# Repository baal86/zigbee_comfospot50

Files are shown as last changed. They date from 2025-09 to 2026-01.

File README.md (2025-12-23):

# Zigbee Comfospot 50
Hardware module to integrate Comfospot 50 ventilation system with ESP32-H2 zigbee enabled controller. Heavily based on https://github.com/lorenzspenger/comfospot-50 but using the ESP32-H2 and Zigbee.

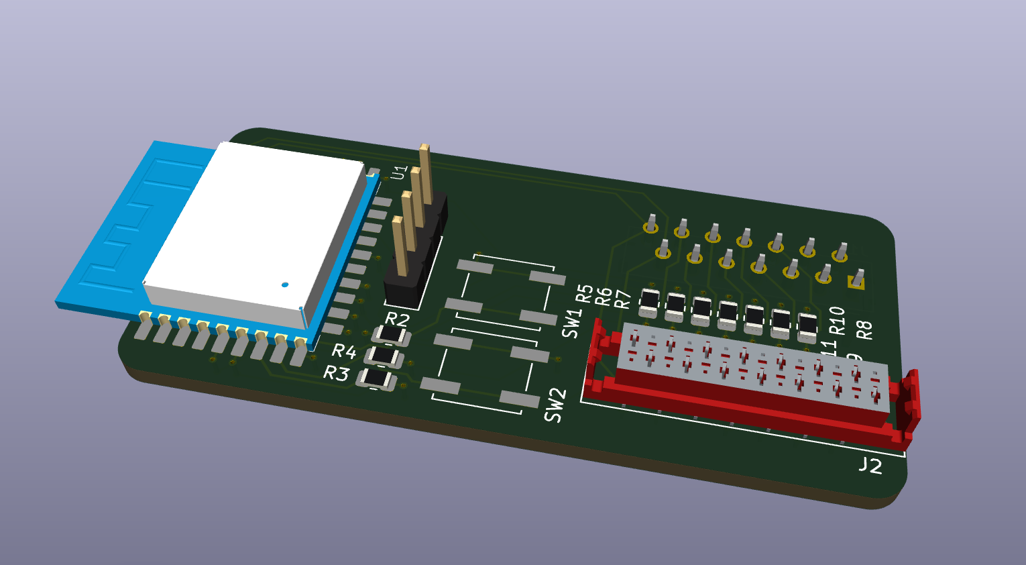
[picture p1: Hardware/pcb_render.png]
PCB Rendering


## Hardware 
Contains a Kicad project to produce the hardware module that plugs inbetwen the Comfospot 50 main board and the user interface panel.

> The latest change to the hardware (shortening the PCB for mechanical fit) was not tested in production. I used a previous revision PCB and shortened it with a file. I will probably never produce the latest version.

## ESPHome
Contains the .yaml file to build the firmware using ESPHome. The `partitions_zb.csv` file is required at the time of writing for zigbee support! OTA is not supported by esphome-zigbee so the image must be programmed using a USB to serial (3.3V TTL levels) converter.

## zigbee2mqtt
Contains the external converter than needs to be provided to Zigbee2MQTT to recognize the device and present it to home assistant. It is currently very basic but is working and the fan unit can be controlled by selecting the desired step.

## TODO
Honestly, it works for me as is right now so don't expect any updates soon. Debugging is quite a pain due to the lack of OTA updates and wireless logging. What I could imagine:

- Support the filter change LED
- More advanced control of fan levels as in https://github.com/lorenzspenger/comfospot-50. My implementation is quite primitive.
- Support control of exhaust/circulation modes.

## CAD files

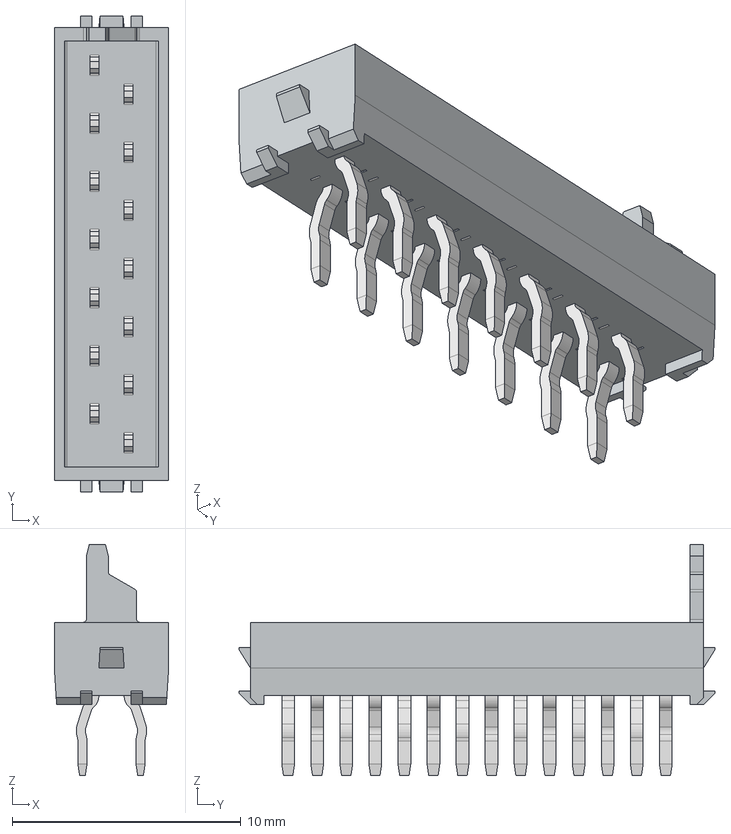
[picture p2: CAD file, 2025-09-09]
Hardware/local.step3d/J_Wurth_WR-MM_690357101472.step
5.00 x 20.8 x 10.1 mm

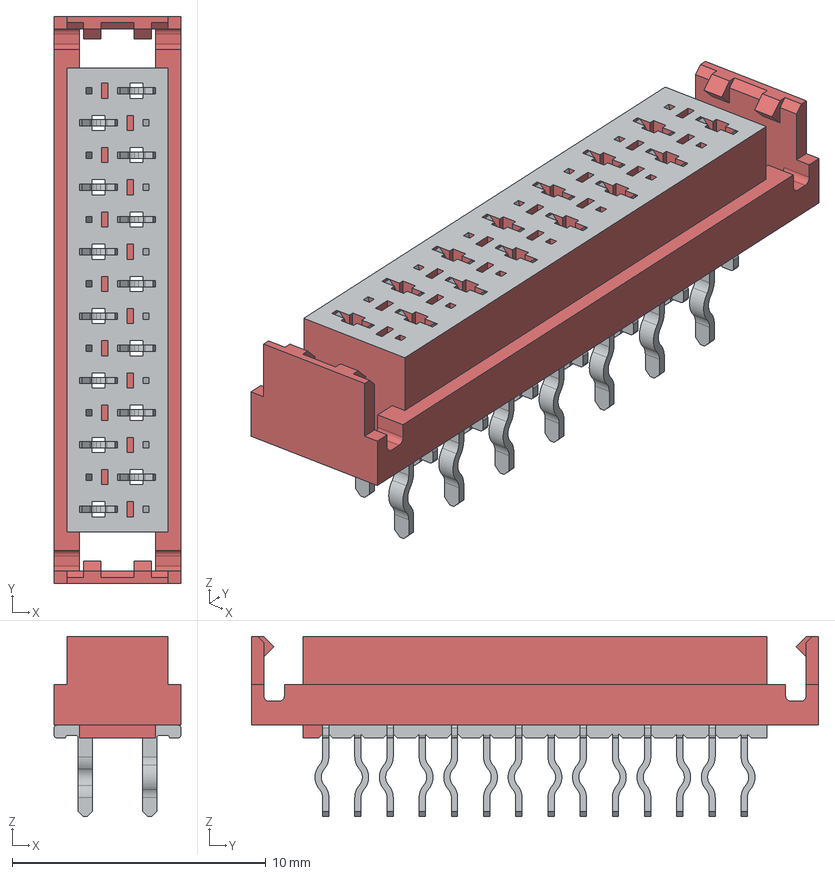
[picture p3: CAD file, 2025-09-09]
Hardware/local.step3d/J_Wurth_WR-MM_690367191472.step
5.00 x 22.4 x 7.10 mm

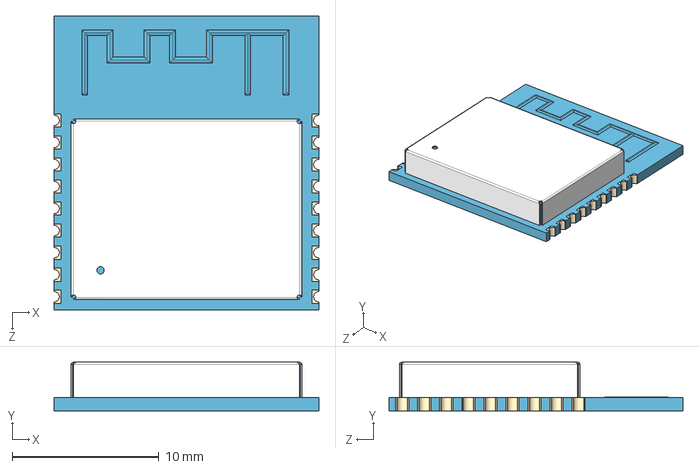
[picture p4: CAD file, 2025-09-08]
Hardware/local.step3d/ESP-WROOM-02.STEP
18.0 x 3.30 x 20.0 mm

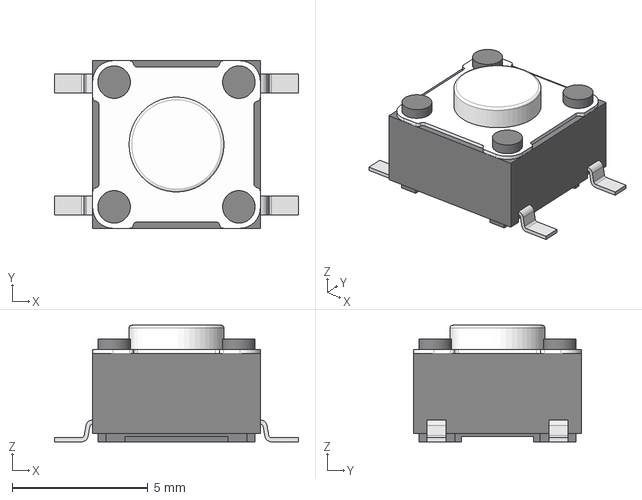
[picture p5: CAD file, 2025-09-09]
Hardware/local.step3d/430182043816.stp
9.00 x 6.20 x 4.30 mm

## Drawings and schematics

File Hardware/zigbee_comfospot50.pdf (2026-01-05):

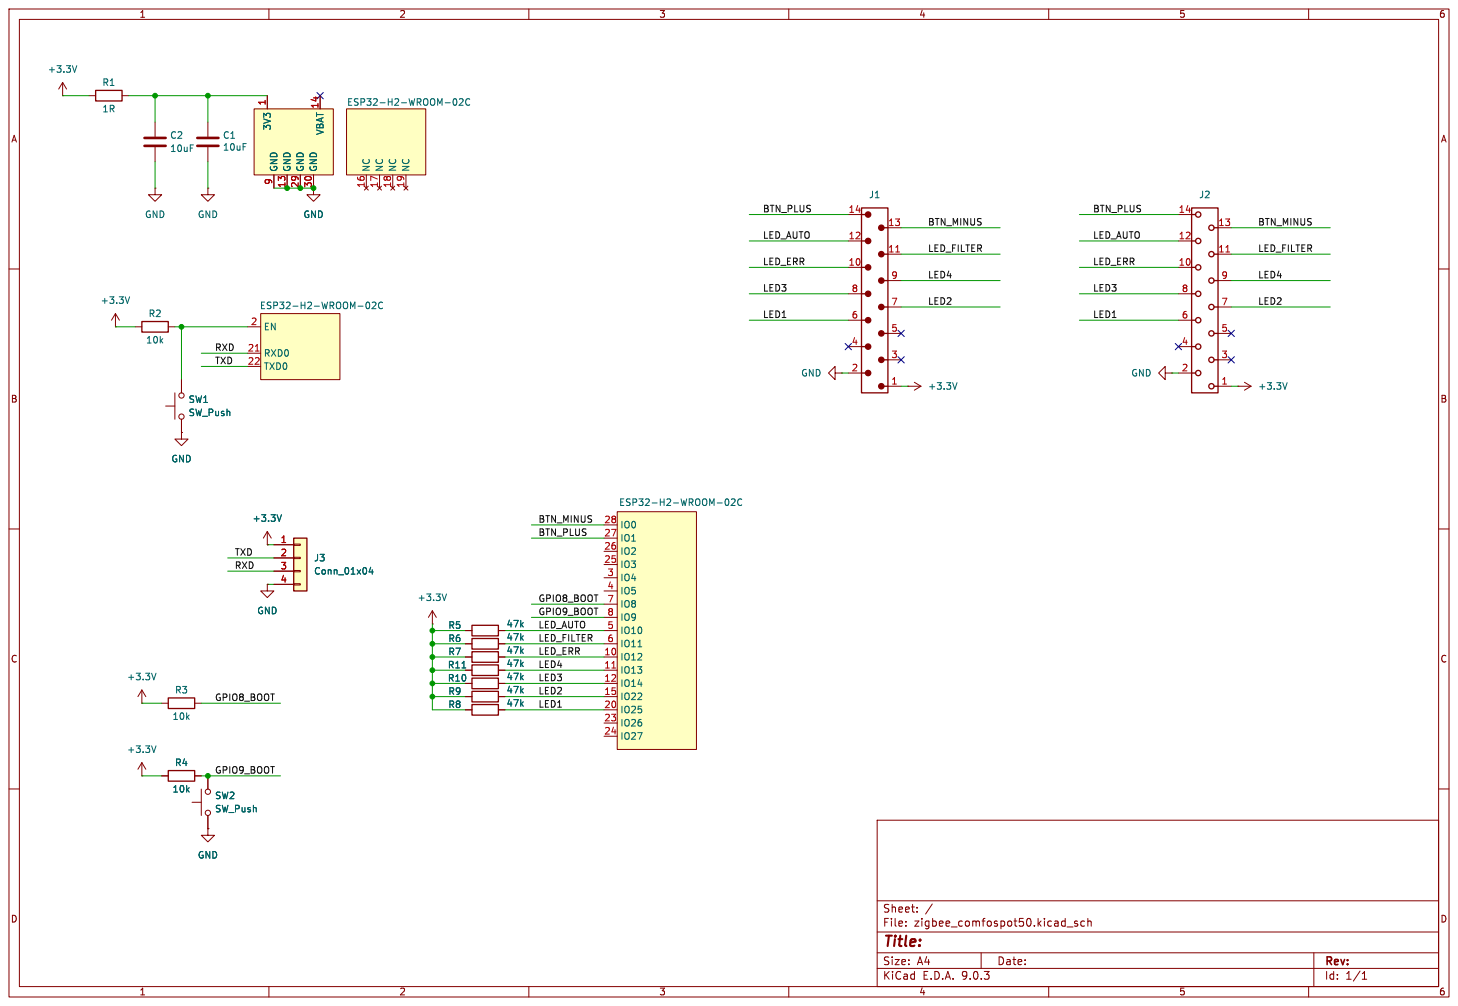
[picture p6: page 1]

9 GND 13 GND 29 GND 30 VBAT 14 GND GND

9 GND 13 GND 29 GND 30 VBAT 14 GND
LED3 3V3

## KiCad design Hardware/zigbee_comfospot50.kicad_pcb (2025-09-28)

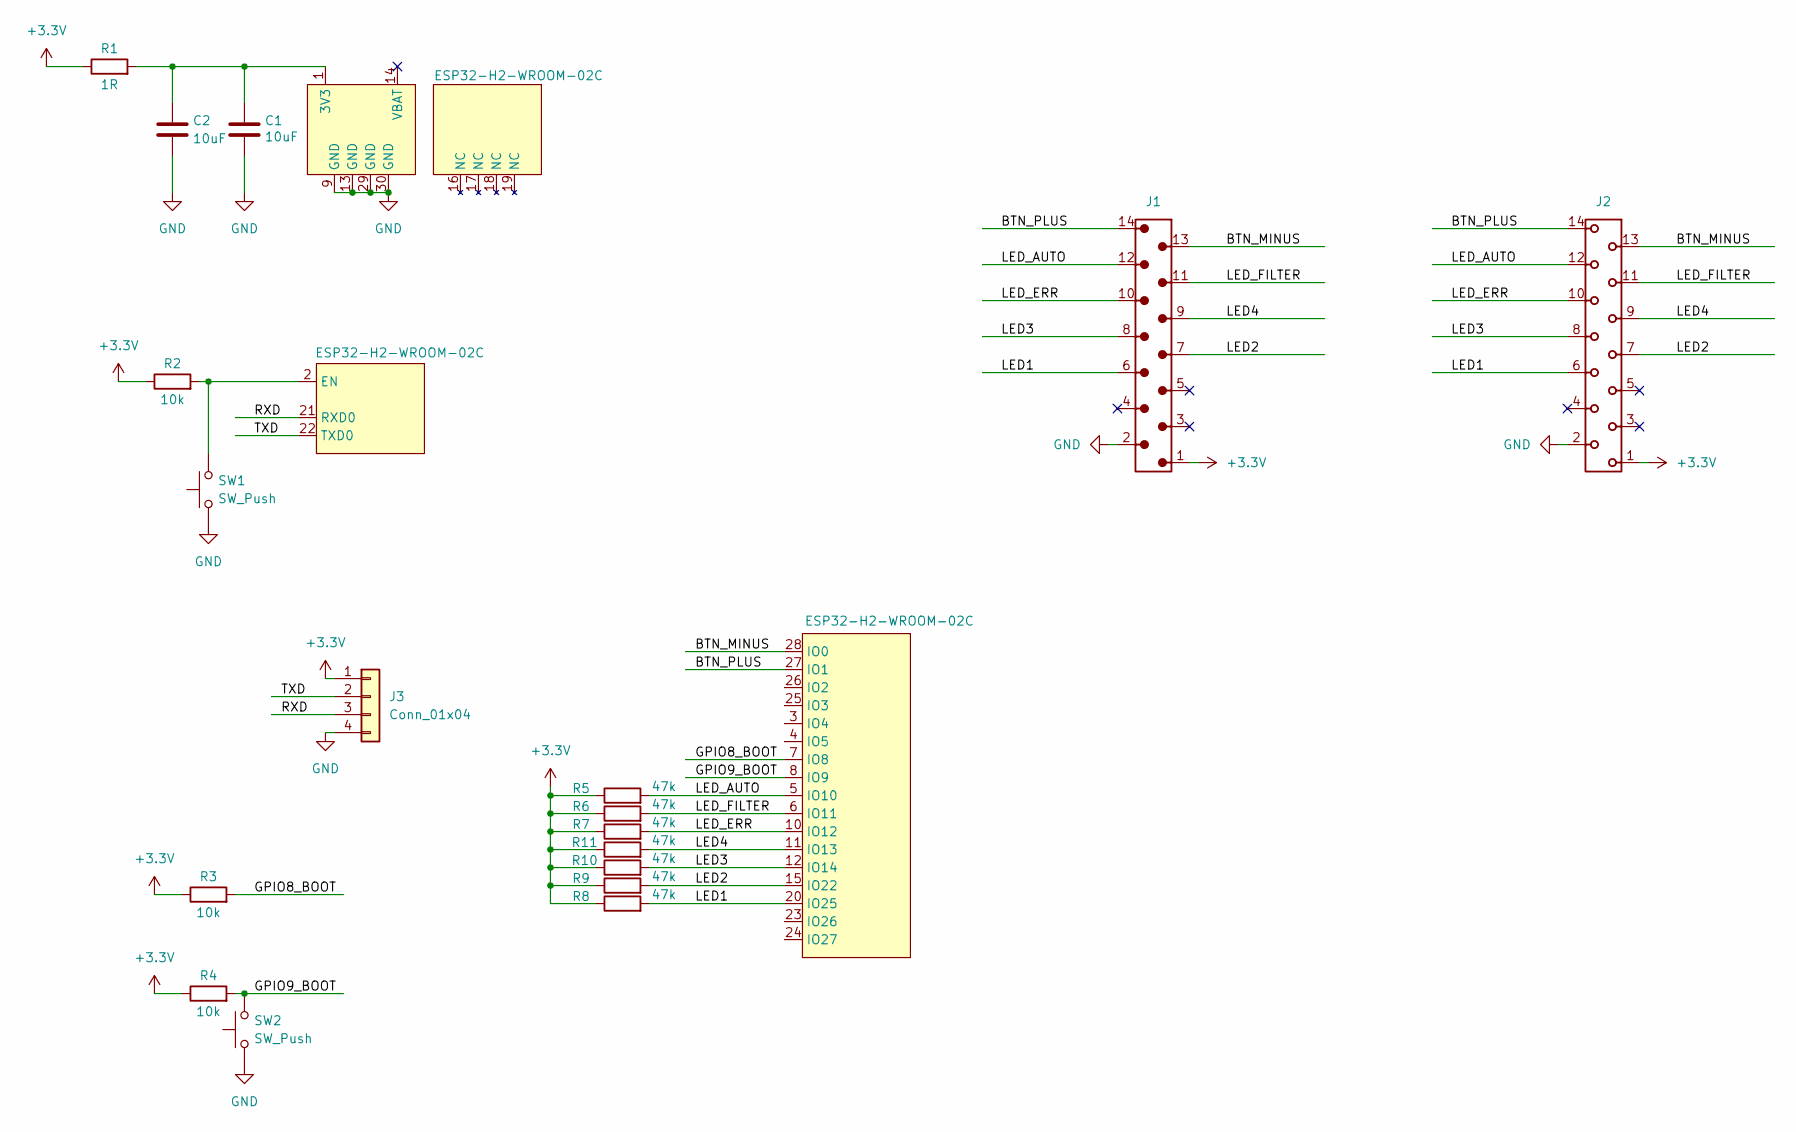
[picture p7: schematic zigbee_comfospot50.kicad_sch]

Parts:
C1, C2: 10uF; C_1206_3216Metric
J1: 690357101472; J_Wurth_WR-MM_690357101472
J2: 690367191472; J_Wurth_WR-MM_690367191472; Working Voltage (V (AC)) 250
J3: Conn_01x04; PinHeader_1x04_P2.54mm_Vertical
R1: 1R; R_0805_2012Metric
R2, R3, R4: 10k; R_0805_2012Metric
R5, R6, R7, R8, R9, R10, R11: 47k; R_0805_2012Metric
SW1, SW2: SW_Push; SW_Push_1P1T_NO_CK_KSC7xxJ
U1: ESP32-H2-WROOM-02C

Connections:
+3.3V: J1.1, J2.1, J3.1, R1.1, R2.1, R3.1, R4.1, R5.1, R6.1, R7.1, R8.1, R9.1, R10.1, R11.1
/BTN_MINUS: J1.13, J2.13, U1.28 (IO0)
/BTN_PLUS: J1.14, J2.14, U1.27 (IO1)
/GPIO8_BOOT: R3.2, U1.7 (IO8)
/GPIO9_BOOT: R4.2, SW2.2, U1.8 (IO9)
/LED1: J1.6, J2.6, R8.2, U1.20 (IO25)
/LED2: J1.7, J2.7, R9.2, U1.15 (IO22)
/LED3: J1.8, J2.8, R10.2, U1.12 (IO14)
/LED4: J1.9, J2.9, R11.2, U1.11 (IO13)
/LED_AUTO: J1.12, J2.12, R5.2, U1.5 (IO10)
/LED_ERR: J1.10, J2.10, R7.2, U1.10 (IO12)
/LED_FILTER: J1.11, J2.11, R6.2, U1.6 (IO11)
/RXD: J3.3, U1.21 (RXD0)
/TXD: J3.2, U1.22 (TXD0)
GND: C1.2, C2.2, J1.2, J2.2, J3.4, SW1.1, SW2.1, U1.9 (GND), U1.13 (GND), U1.29 (GND), U1.30 (GND)
unnamed: C1.1, C2.1, R1.2, U1.1 (3V3)
unnamed: R2.2, SW1.2, U1.2 (EN)

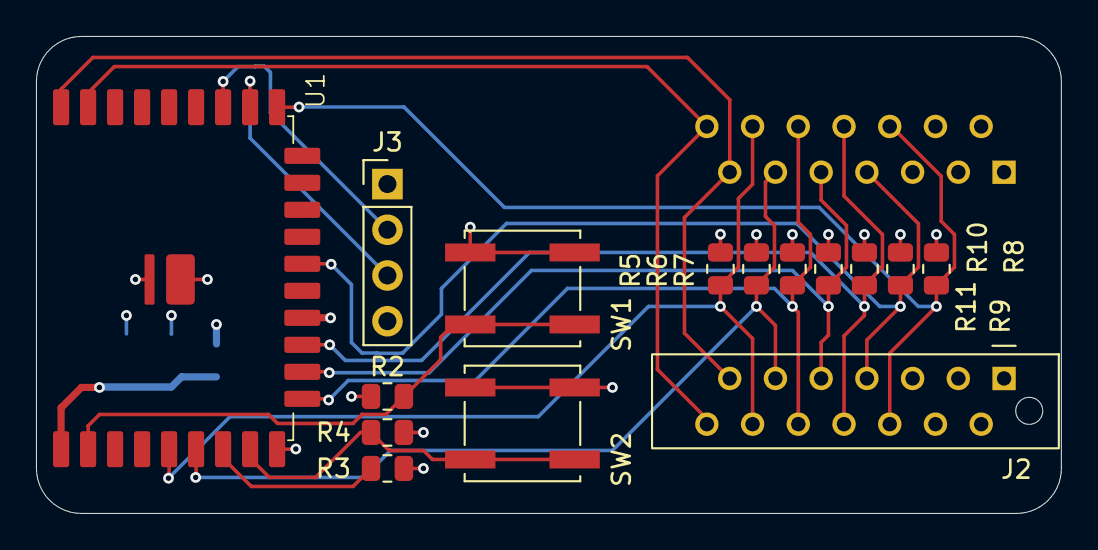
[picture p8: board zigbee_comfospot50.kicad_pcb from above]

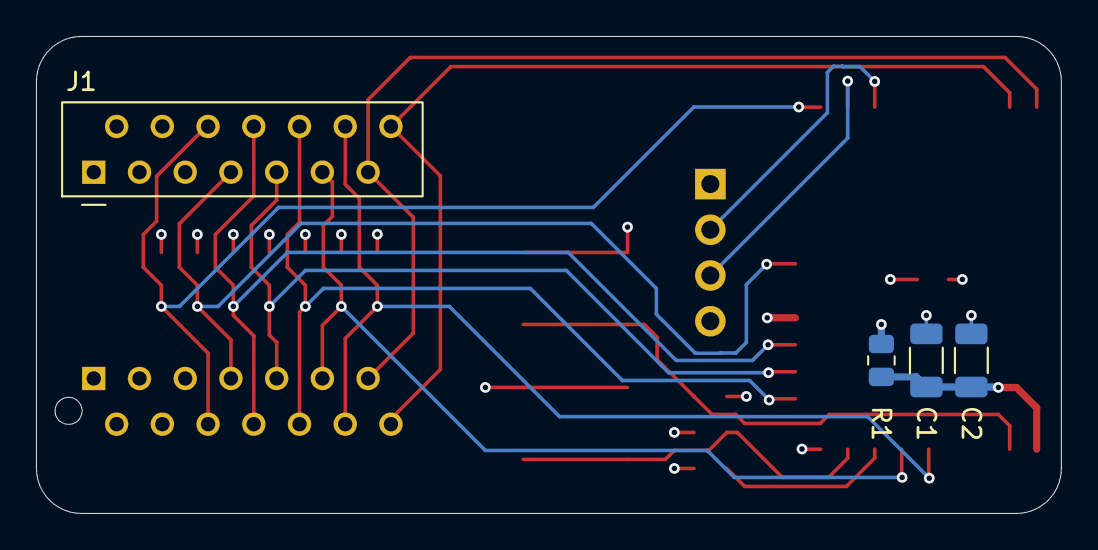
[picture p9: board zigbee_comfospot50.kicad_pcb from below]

Board: 4 copper layers, 56.9 x 26.5 mm, 19 parts (4 on the bottom side), 17 nets.

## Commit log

2025-09-08 Added initial KiCAD Files
    [zigbee_comfospot50.kicad_pcb, zigbee_comfospot50.kicad_sch]
2025-09-08 Added H2 module
    [zigbee_comfospot50.kicad_sch]
2025-09-08 added signal names
    [zigbee_comfospot50.kicad_sch]
2025-09-08 3D model
    [ESP-WROOM-02.STEP, zigbee_comfospot50.kicad_pcb, zigbee_comfospot50.kicad_sch]
2025-09-09 Added correct connector
    [J_Wurth_WR-MM_690357101472.step, J_Wurth_WR-MM_690367191472.step]
2025-09-09 Started routing
    [430182043816.stp, zigbee_comfospot50.kicad_pcb, zigbee_comfospot50.kicad_sch]
2025-09-28 Shortened PCB to fit Comfospot 50 available space. NOT YET TESTED in HW.
    [zigbee_comfospot50.kicad_pcb]
2025-12-23 Add partitions_zb.csv for ESPHome configuration
    Required for esphome zigbee on H2.
    [partitions_zb.csv]
2025-12-23 Added PCB render
2025-12-23 Update README.md
    Added picture of PCB
2026-01-05 Added PDF of schematics
